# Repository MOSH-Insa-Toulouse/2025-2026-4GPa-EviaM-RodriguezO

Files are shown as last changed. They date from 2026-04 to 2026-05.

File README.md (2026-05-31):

# 2025-2026-4GPa-EviaM-RodriguezO

# Projet Capteur
Dans le cadre du UF « Du capteur au banc de test », ce travail doit concevoir et mettre en œuvre un système de mesure de déformation par un capteur en graphite, lowtech, et comparer son débrouillement à un autre capteur commercial.
Le principe de fonctionnement du capteur en graphite est expliqué comme: La mine de crayon est déposée mécaniquement à la surface du papier, où elle s’insère partiellement dans sa structure poreuse. Cette opération conduit à la formation d’une piste conductrice constituée de particules de graphite dispersées au sein des fibres cellulosiques du papier, le liant jouant principalement un rôle isolant. L’ensemble des particules établit un réseau conducteur dont la continuité dépend du nombre de contacts électriques entre les grains de graphite. Le état du capteur dédnad, la géométrie dépend de la manière dont on s'en sert: une traction tend à éloigner les particules et à réduire les points de contact, tandis qu’une compression favorise leur rapprochement et augmente les connexions conductrices. Ces variations de connectivité se traduisent par une modification mesurable de la résistance électrique de la piste.
La figure suivante illustre, dans la partie c), le fonctionnement du réservoir de graphite sur le feuille:
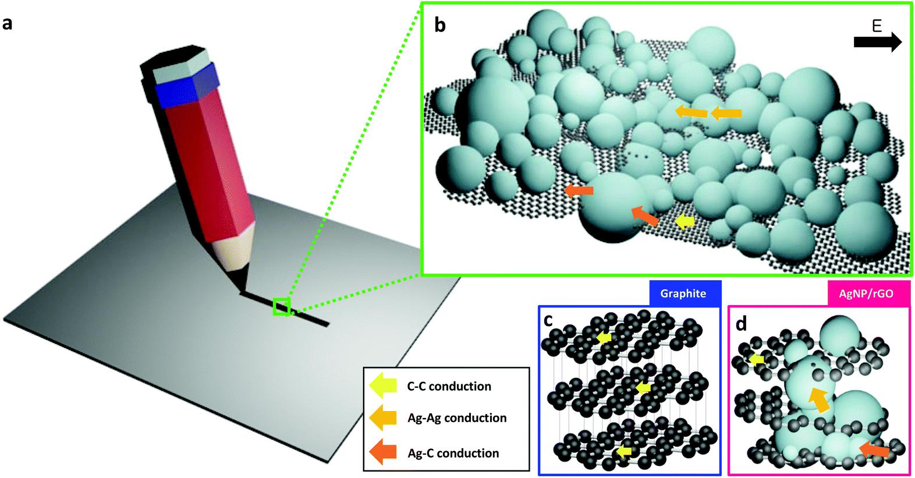
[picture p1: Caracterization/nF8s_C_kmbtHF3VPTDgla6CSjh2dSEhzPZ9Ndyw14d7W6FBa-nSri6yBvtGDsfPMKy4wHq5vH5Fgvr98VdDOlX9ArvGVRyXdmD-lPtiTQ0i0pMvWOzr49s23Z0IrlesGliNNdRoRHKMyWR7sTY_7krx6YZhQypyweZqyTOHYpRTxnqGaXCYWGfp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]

<p align="center">
Répresentation du graphite
</p>
## Objectifs du projet
- Concevoir et réaliser un shield Arduino intégrant un capteur de contrainte en graphite de conception simple afin d'en déterminer les caractéristiques.
- Concevoir un circuit électronique analogique capable de transmettre des données via un microcontrôleur à une application Android, ainsi que la mise en place d'un banc d'essai.
- Élaboration de la datasheet du capteur.

## Contexte
Nous avons fabriqué un capteur de déformation en exploitant la conductivité d'une couche de graphite appliquée sur une feuille de papier, créant ainsi un capteur grâce aux propriétés granulaires acquises qui dépendent également de la composition du crayon.

Lorsque le capteur est comprimé, la résistance diminue en raison de la proximité des molécules de graphite, ce qui augmente la conductivité. Lorsqu'il est étiré, c'est l'inverse qui se produit, ce qui augmente la résistance.

C'est sur la base de ce comportement que l'on cherche à déduire l'angle d'inclinaison afin de connaître et de rendre compte des caractéristiques du capteur.

Ce projet est basé du travail trouvé dans: Lin, CW, Zhao, Z., Kim, J. et al. (2014); Nature, "Pencil Drawn Strain Gauges and Chemiresistors on Paper".

## Livrables

### KiCad
Pour créer la carte qui nous permettrait de disposer de notre circuit, il a fallu réaliser la conception à l'aide du logiciel KiCad, en tenant compte de tous les composants et en utilisant les connexions convenues en cours.


<p align="center">
Schéma du circuit sur KiCad.
</p>

Après avoir déterminé les connexions du circuit, nous avons pu passer à la conception du circuit imprimé, qui devait tenir compte de certains aspects tels que l'optimisation de l'espace, la largeur minimale des pistes tant pour la transmission des données que pour l'alimentation, la résolution possible lors de l'impression, ainsi que la disposition des composants afin d'éviter d'avoir à souder trop de ponts.


<p align="center">
Dessin du circuit imprimé sur KiCad.
</p>

Voir la documentation dans le dossier **Fichiers Kicad**

### Shield
Le modèle 3D du système créé, y compris sa couverture, est présenté dans l'image suivante.


<p align="center">
Système pret pour être implementé
</p>

Afin de mieux présenter les composants, nous allons nous appuyer sur la figure suivante, qui nous permet de voir tous les éléments qui composent le projet, à commencer par le microcontrôleur Arduino, qui assure la conversion des signaux analogiques en signaux numériques ainsi que le contrôle et la coordination des différentes fonctions ; le capteur low-tech qui sera mis à l'épreuve ; le capteur commercial, afin de pouvoir le comparer à un produit en principe mieux adapté à l'objectif ; l'encodeur, qui permet de sélectionner les fonctions et de les commander manuellement; l'écran OLED, qui nous permet de disposer d'une interface pour sélectionner et contrôler manuellement les fonctions, ainsi que pour afficher les données transmises par les capteurs ; et enfin, le module Bluetooth, qui permet de recevoir les données des capteurs et de les afficher dans l'application mobile.



<p align="center">
Dispositif sans boîtier de protection
</p>

Ces images peuvent être visualisées dans le dossier **3D designs**

### Code Arduino
Le code Arduino a pour but de permettre à l'utilisateur d'interagir avec tous les composants du système : 

- Le contrôle du servomoteur
  - Modification de l'angle d'inclinaison.
  
- Le réglage du potentiomètre numérique
  - Ajustement du gain du système.

- L'affichage local
  - Visualisation en temps réel des données sur l'écran OLED.

- La communication Bluetooth
  - Transmission des données des deux capteurs vers l'application mobile.
 > [!TIP]
> Vous pouvez utiliser l'encodeur numérique pour naviguer dans le menu de l'écran OLED et sélectionner les paramètres souhaités. Cliquez pour accéder au menu de votre choix et maintenez le bouton de l'encodeur enfoncé pour revenir au menu principal.
### Logiciel pour portables
Grâce à la plateforme MIT App Inventor, nous avons conçu une application dont la fonction principale était de pouvoir recevoir et représenter graphiquement les données captées par un ou les deux capteurs simultanément, ainsi que de pouvoir envoyer des données pour commander à la fois le servomoteur et le potentiomètre numérique ; toutefois, l'envoi de données n'a pas eu lieu.
<p align="center">
 
</p>
<p align="center">
Application crée, face-avant au démarrage / avec les fonctions.
</p>

Le code des blocs derrière l'interface est visible sur les images suivantes.



<p align="center">
Bloques de code.
</p>

Voir la documentation dans le dossier **Application Mobile**.
### Datasheet
Toutes les spécifications du capteur, sa caractérisation et sa simulation dans le logiciel LTspice sont disponibles dans la fiche technique: [Datasheet](Datasheets/Datasheet_MOSH_EN.pdf)
# Caractérisation du système 
La réponse du capteur à la manipulation a été caractérisée à l'aide de deux types différents de feuilles de graphite : de type HB et de type 3HB. En faisant varier la résistance du potentiomètre, on a constaté que la tension maximale du capteur était atteinte lorsque le potentiomètre avait un gain de 225. 
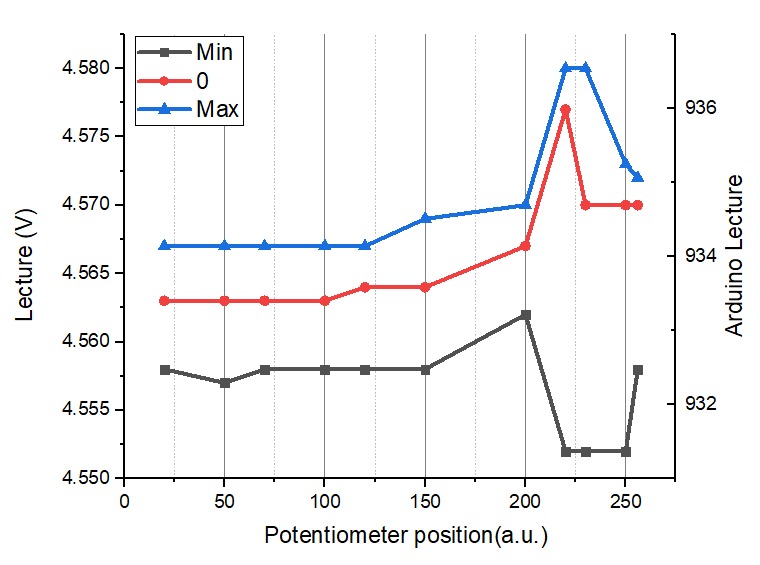
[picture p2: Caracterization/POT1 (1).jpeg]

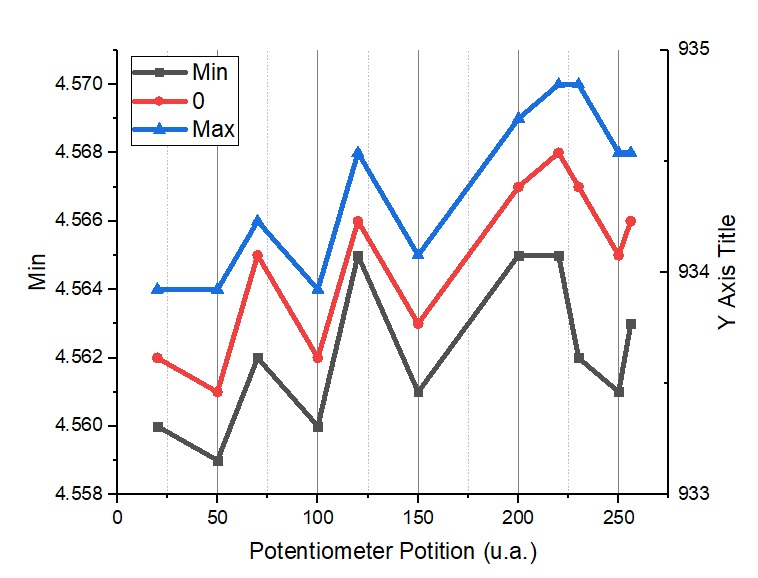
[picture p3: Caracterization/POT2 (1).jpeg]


<p align="center">
Caractérisation du capteur.
</p>

## Conclusion 
Ce projet nous a permis de voir concrètement comment exploiter un phénomène physique pour mesurer un changement au sein d'un système ; en recourant à des moyens simples et en tirant parti de propriétés microscopiques, nous avons pu concevoir un dispositif qui nous a permis de collecter et de traiter des données de manière relativement simple.

Cependant, le projet a également mis en évidence les limites de l'utilisation de ce type de systèmes low-tech, à commencer par la capacité à reproduire les mêmes résultats, car il existe un grand nombre de variables à prendre en compte, telles que l'état du papier, la composition du graphite, la qualité du trait tracé ; toutes ces variables affectent le fonctionnement et l'étalonnage du capteur, et sont difficiles à normaliser manuellement. Et, parallèlement, certaines de ces variables étant très sensibles à l'utilisation, cela finit par nuire à la fiabilité des données recueillies au fil du temps-
Pour toute question concernant les caractéristiques du capteur ou en cas de problèmes techniques, n'hésitez pas à contacter :
- Octavio Rodriguez : orodriguez-r@insa.toulouse.fr
- Manuel Evia : mevia@insa-toulouse.fr

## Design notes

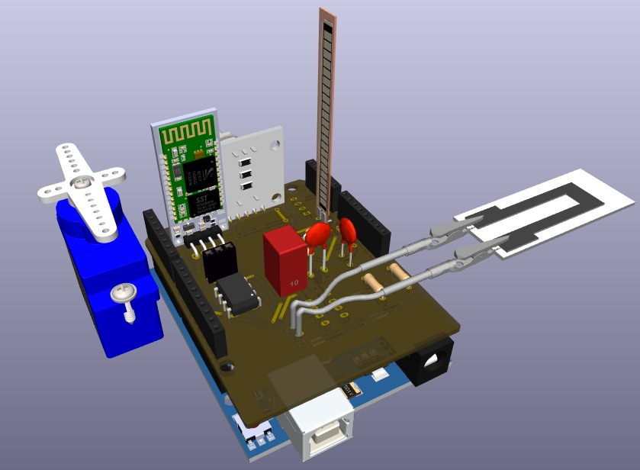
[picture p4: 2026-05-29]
3D designs/Shield/Système.png

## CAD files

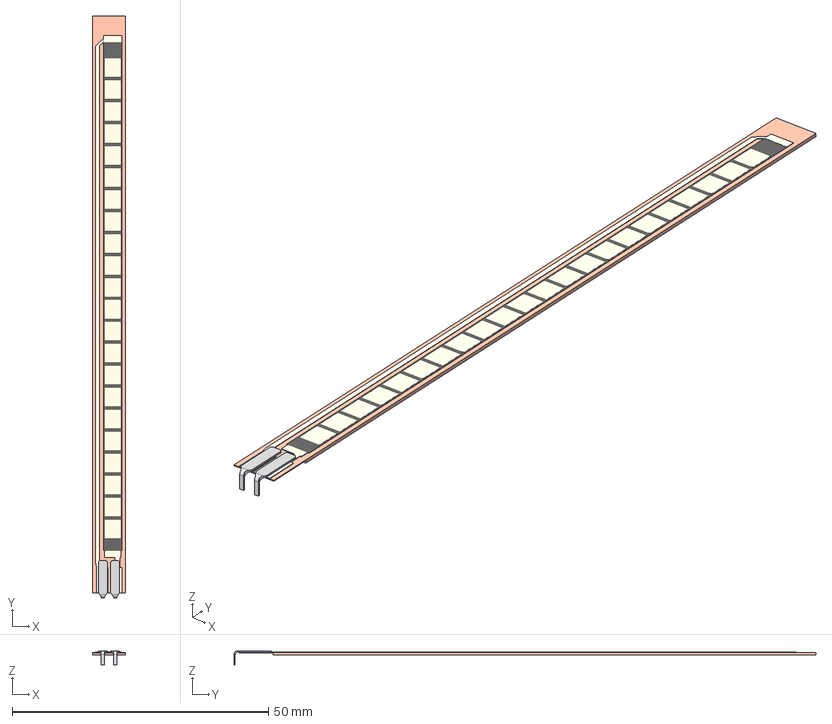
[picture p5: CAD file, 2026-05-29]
3D designs/Composants/FS-L-0095-103-ST - Assembly.stp
6.45 x 113.5 x 2.77 mm
FS-L-0095-103-ST - Base
FS-L-0095-103-ST - Top

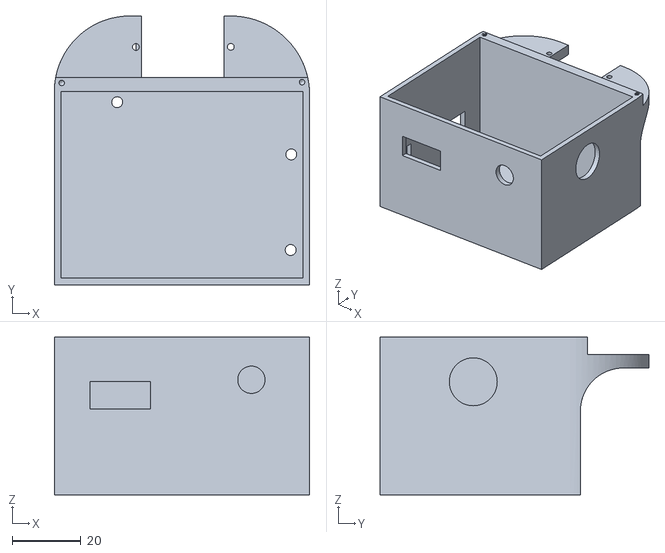
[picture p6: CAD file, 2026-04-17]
3D designs/Shield/Body_Shield (1).stl
74.5 x 78.5 x 46.0

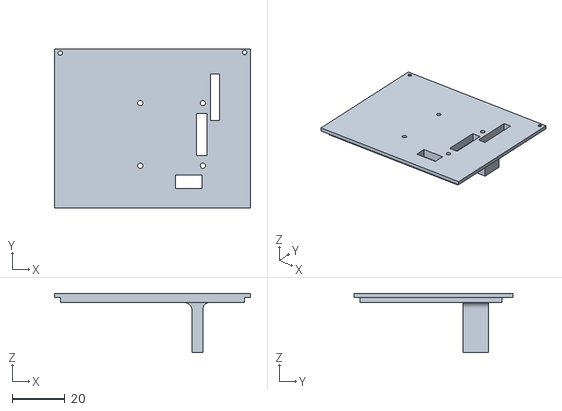
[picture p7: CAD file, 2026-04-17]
3D designs/Shield/Roof_Shield (1).stl
74.5 x 60.5 x 22.5

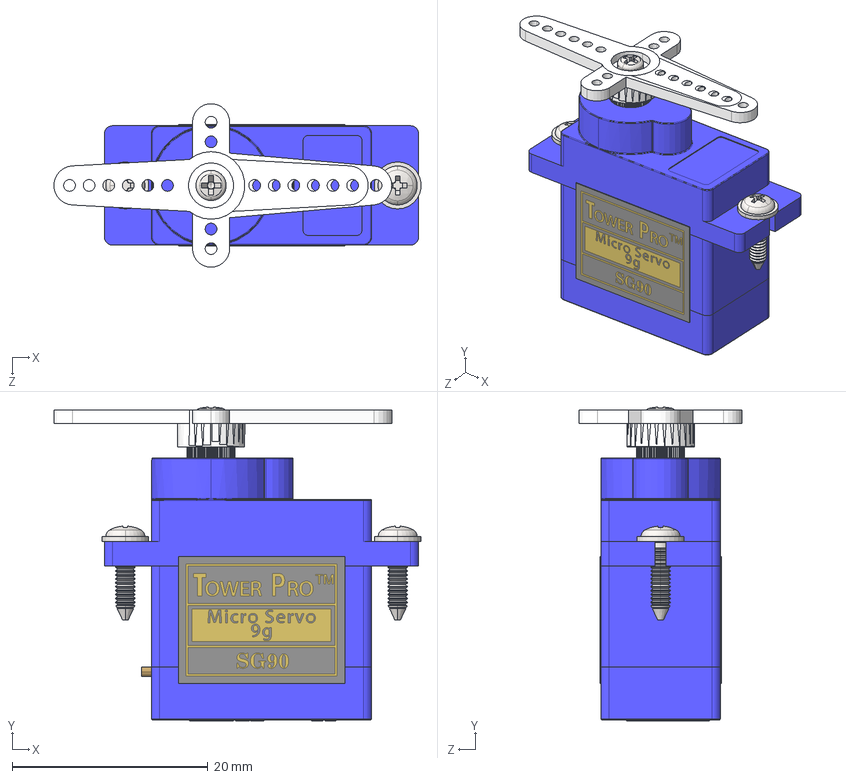
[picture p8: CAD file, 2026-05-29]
3D designs/Composants/SG90 - Micro Servo 9g - Tower Pro.STEP
37.5 x 32.0 x 16.7 mm
SG90 - Micro Servo 9g - Tower Pro.1_Pe㌢
SG90 - Micro Servo 9g - Tower Pro.2_Pe㌢
SG90 - Micro Servo 9g - Tower Pro.3_Pe㌢
SG90 - Micro Servo 9g - Tower Pro.4_Pe㌢
SG90 - Micro Servo 9g - Tower Pro.5_BS EN ISO 7045 - M2 x 8 - Z - 8S x 2
SG90 - Micro Servo 9g - Tower Pro.6_BS EN ISO 7045 - M2 x 4 - Z - 4S

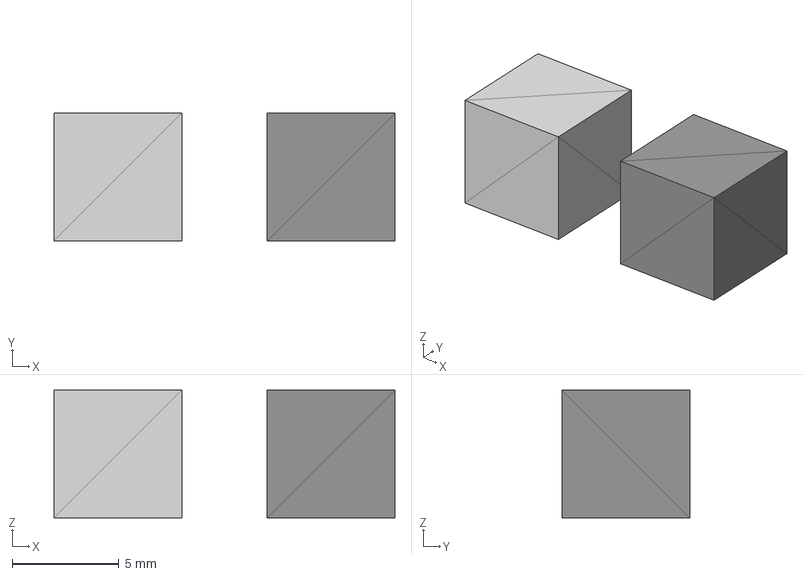
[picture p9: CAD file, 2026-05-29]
3D designs/Composants/Cuerpo1.step
16.0 x 6.00 x 6.00 mm

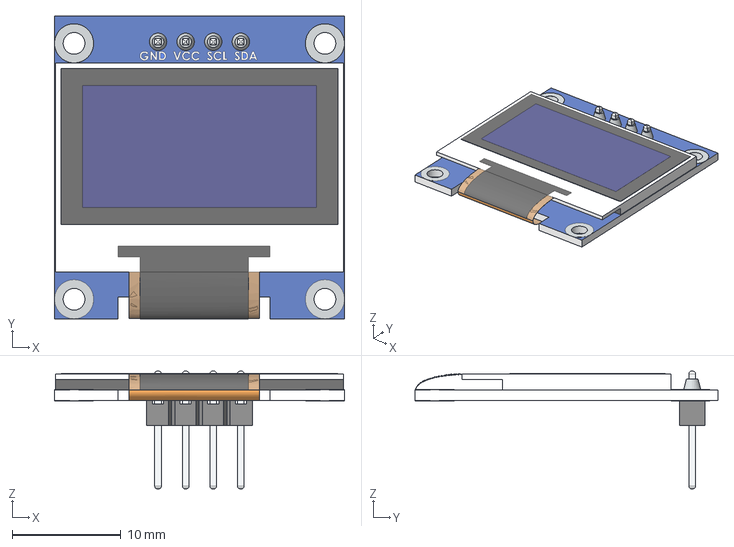
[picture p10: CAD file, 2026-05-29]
3D designs/Composants/OLED-128x64-0.96.step
26.7 x 27.9 x 10.8 mm

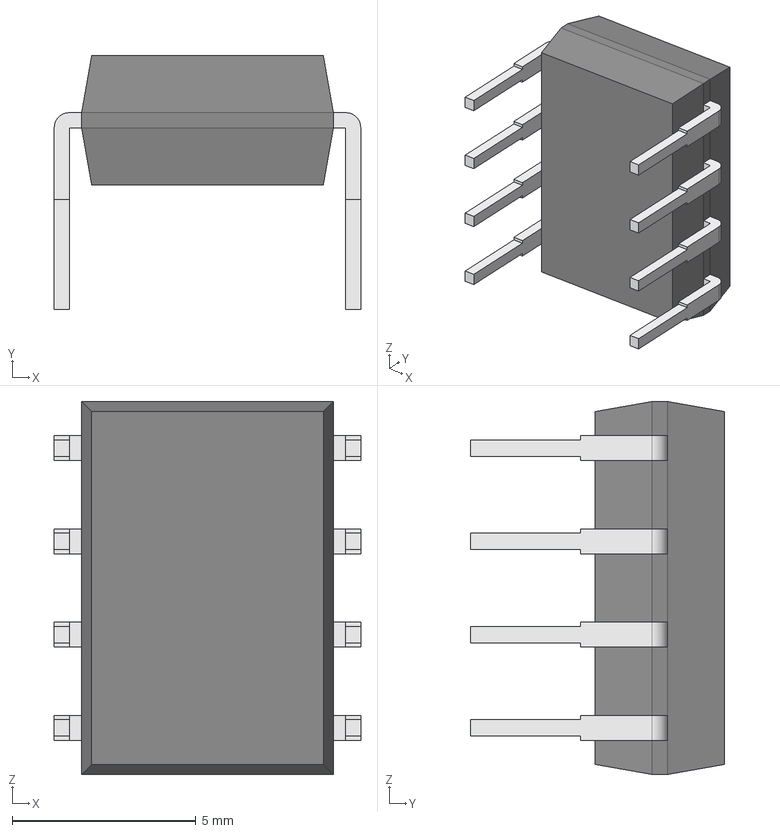
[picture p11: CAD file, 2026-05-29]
3D designs/Composants/LTC1050CN8.step
8.35 x 6.93 x 10.2 mm
Body001 (Mirror #1) x 5

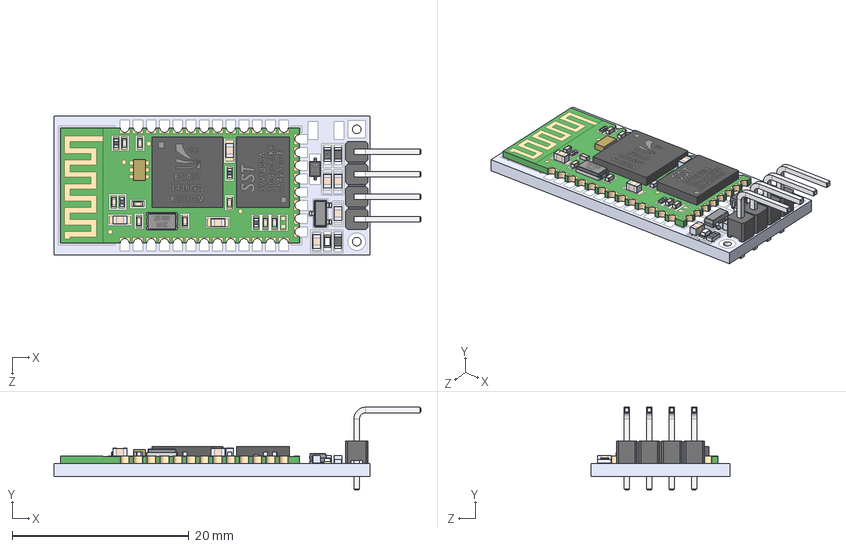
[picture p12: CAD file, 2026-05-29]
3D designs/Composants/HC06_Modulo.STEP
41.5 x 9.36 x 15.8 mm
HC05_Pcb
HC05_06
C0603 x 7
R0402_По умолчанию x 4
C0402 x 9
QSMD7.0x5.0x1.3
Led 0603 Smd
R0603 222_По умолчанию x 2
R0603 103_По умолчанию
SOT23-3
SOD323 S4
Pines_90_4p

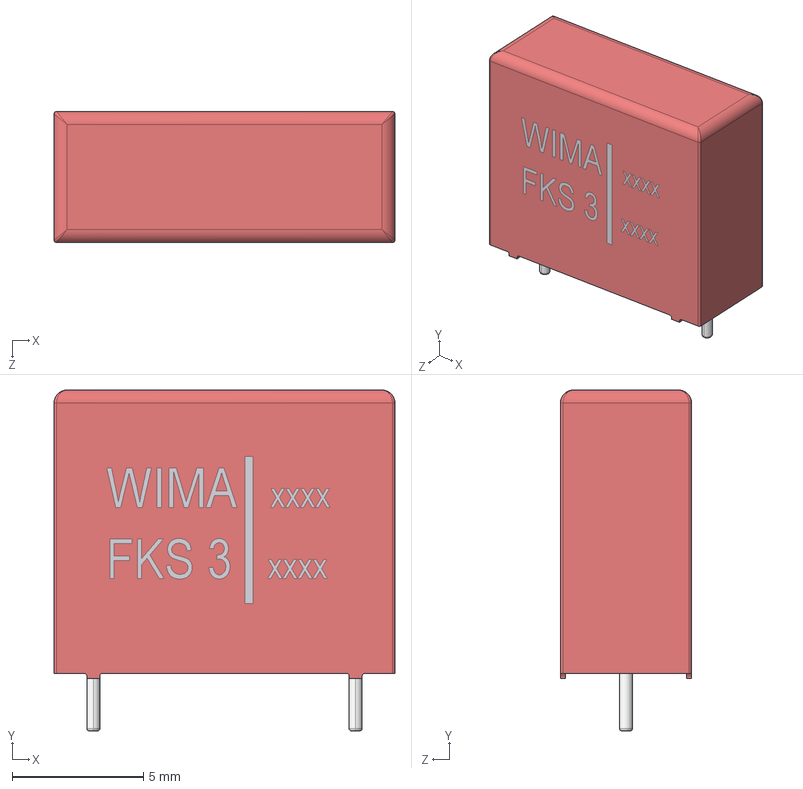
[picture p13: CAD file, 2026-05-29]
3D designs/Composants/FKS3 PCM10 W5 H11 L13.STEP
13.0 x 13.0 x 5.00 mm

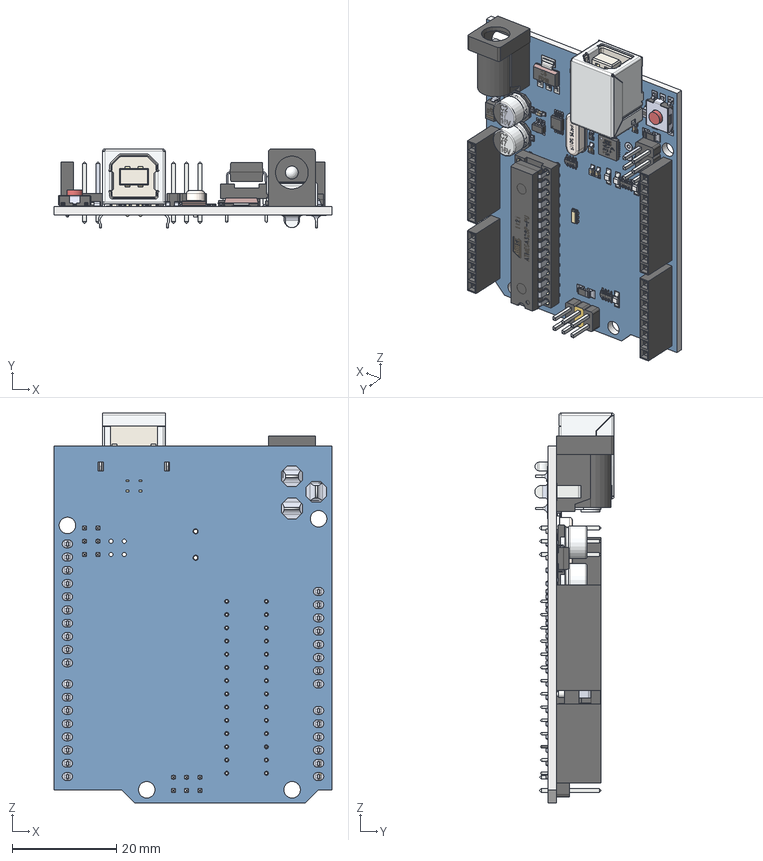
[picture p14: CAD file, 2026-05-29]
3D designs/Composants/Arduino Uno.step
53.3 x 15.2 x 74.9 mm

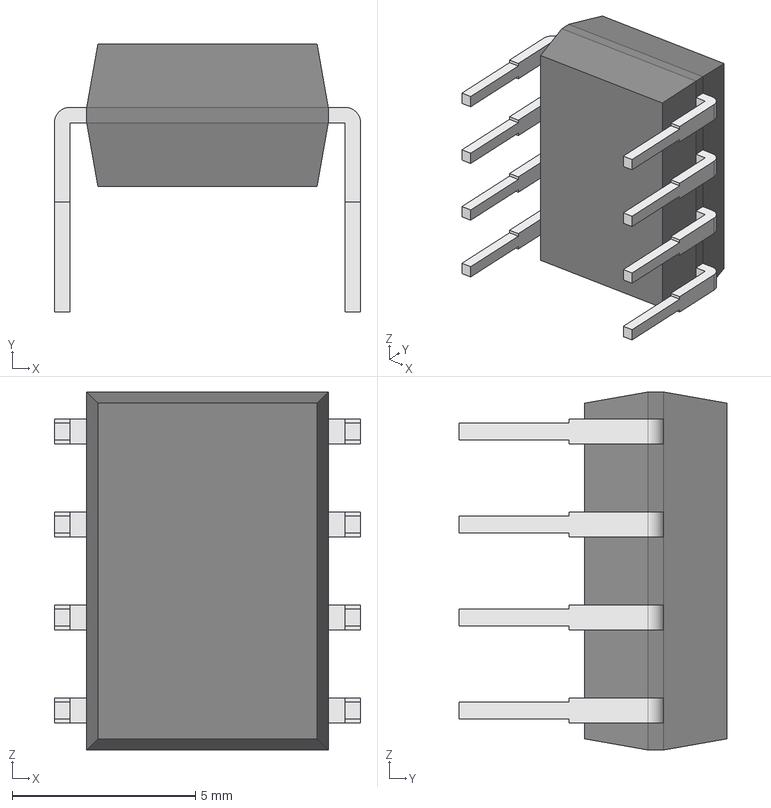
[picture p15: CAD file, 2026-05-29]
3D designs/Composants/MCP41010-I_P.step
8.37 x 7.32 x 9.78 mm
Body001 (Mirror #1) x 5

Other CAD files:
3D designs/Composants/CapteurGraphite.step
3D designs/Composants/Cuerpo1.stl

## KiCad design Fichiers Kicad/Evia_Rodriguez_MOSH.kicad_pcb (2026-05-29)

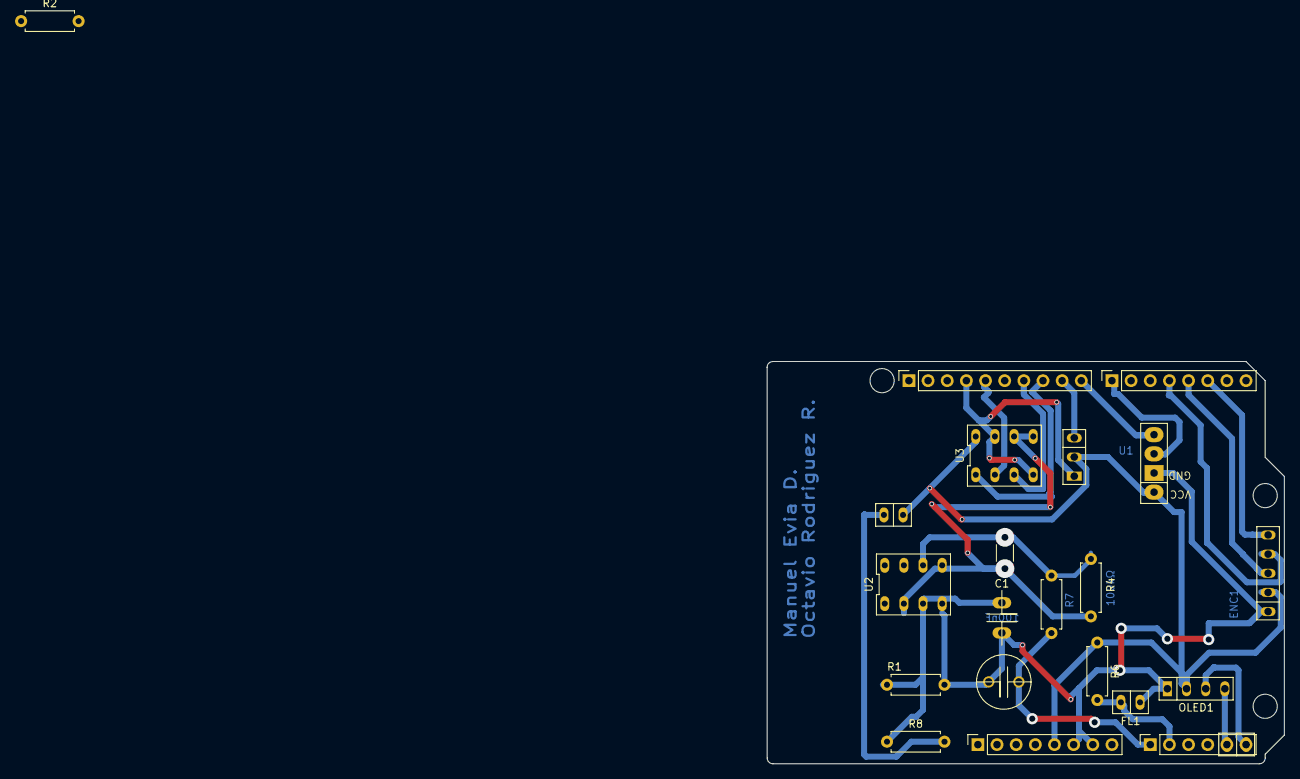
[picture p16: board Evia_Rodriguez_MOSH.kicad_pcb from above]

Board: 2 copper layers, 68.6 x 53.3 mm, 25 parts (0 on the bottom side), 19 nets.

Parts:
C1, C3: 100nF; CPA_2
C2: 1µF; C_1808_4520Metric
ENC1: SIP-5
FL1, FL1#2: SIP-2
GS1: SIP-2
J1: Power; PinSocket_1x08_P2.54mm_Vertical
J2: Digital/PWM; PinSocket_1x10_P2.54mm_Vertical
J3: Analog; PinSocket_1x06_P2.54mm_Vertical
J4: Digital/PWM; PinSocket_1x08_P2.54mm_Vertical
M1: Motor_Servo; SIP-3
MH1, MH3, MH4: MountingHole_3.2mm
OLED1: SIP-4
R1, R4: 100kΩ; R_Axial_DIN0207_L6.3mm_D2.5mm_P7.62mm_Horizontal
R2, R6, R8: 10kΩ; R_Axial_DIN0207_L6.3mm_D2.5mm_P7.62mm_Horizontal
R7: 1kΩ; R_Axial_DIN0207_L6.3mm_D2.5mm_P7.62mm_Horizontal
U1: Bluetooth_HC05
U2: LTC1050ACN8_PBF; MPC41010
U3: MCP41010; MPC41010

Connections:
+5V: ENC1.2 (+), GS1.1, J1.5, M1.2 (+), OLED1.2 (VCC), R6.1, U1.1 (VCC), U2.7 (V+), U3.8 (VDD)
A1: FL1#2.1, J3.2, R6.2
A4: J3.5, OLED1.4 (SDA)
A5: J3.6, OLED1.3 (SCL)
ADC: C3.1, J3.1, R7.2
D2: ENC1.5 (CLK), J4.6
D3: ENC1.3 (SW), J4.5
D4: ENC1.4 (DT), J4.4
D7: J4.1, U1.3 (TXD)
D8: J2.10, U1.4 (RXD)
D9: J2.9, M1.1 (PWM)
D10: J2.8, U3.1 (~CS)
D11: J2.7, U3.3 (SI)
D13: J2.5, U3.2 (SCK)
GND: C1.2, C3.2, ENC1.1 (GND), FL1#2.2, J1.6, J1.7, J2.4, M1.3 (-), OLED1.1 (GND), R1.2, U1.2 (GND), U2.4 (V-), U3.4 (VSS), U3.7 (PB0)
unnamed: GS1.2, R8.2
unnamed: C1.1, R1.1, R8.1, U2.3 (+IN)
unnamed: C2.2, R4.2, R7.1, U2.6 (OUT)
R2+: C2.1, R4.1, U2.2 (-IN), U3.5 (PA0), U3.6 (PW0)

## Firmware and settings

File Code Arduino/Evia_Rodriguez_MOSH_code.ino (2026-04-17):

#include <Adafruit_SSD1306.h>
#include <SPI.h>
#include <Servo.h>
#include <Wire.h>
#include <SoftwareSerial.h>


/* PINOUT */
#define PIN_OPAMP A0
#define PIN_FLEX  A1
#define ENC_CLK   2
#define ENC_SW    3
#define ENC_DT    4
#define BT_STATE  6  
#define PIN_SERVO 9
#define PIN_CS    10 

#define MCP_WRITE 0b00010001
#define GRAPH_X0 20   // 
#define GRAPH_Y0 0    // Variables nécessaires pour définir les dimensions 
#define GRAPH_W 108   // des graphiques en fonction de la taille de l'écran OLED
#define GRAPH_H 54    
/* ------------------ OBJETS-----------*/
SoftwareSerial mySerial(7,8);
Servo servoMotor;
Adafruit_SSD1306 display(128, 64, &Wire, -1);
String inputBuffer = "";
String serialBuffer = "";

volatile long encoderPos = 0;
volatile int lastStateCLK;
int menuIndex = 0;
int graphX = 0;
int lastY = 32;
int servoPos = 0;
int potValue = 128;  


enum Mode {
  MENU,
  ANALOG_A0,
  ANALOG_A1,
  SERVO_MODE,
  POT_MODE,
  BT_MODE,
  //MORSE_MODE
};

Mode currentMode = MENU;

/* Servo & Pot */
bool btWasEverConnected = false;
bool receivingCommand = false;
bool lastButtonStateMorse = false;
bool resetTriggered = false;
bool btConnected = false;
bool lastBtState = false;
bool buttonState = false;
bool lastButtonState = false;
bool click = false;

unsigned long pressStartTime = 0;
long lastEnc = 0;/* Encoder */

/*-------------Function Potentiomètre------------------*/
void writePot(byte value) {
  digitalWrite(PIN_CS, LOW);
  SPI.transfer(MCP_WRITE);
  SPI.transfer(value);
  digitalWrite(PIN_CS, HIGH);
}
/*AAAAAAAA*/
void handleSerial() {  //Function pour détecter des commands vers l'arduino

  while (Serial.available() || mySerial.available()) {

    char c;

    if (Serial.available()) c = Serial.read();
    else c = mySerial.read();

    /*-------- SERVO COMMANDS FUNCTION --------*/
    if (c == 'S') {

      // Esperar siguiente carácter
      while (!Serial.available() && !mySerial.available());
      if (Serial.available()) c = Serial.read();
      else c = mySerial.read();
      if (c == '1') {
        servoPos -= 5;
      }
      else if (c == '2') {
        servoPos += 5;
      }

      servoPos = constrain(servoPos, 0, 180);
      servoMotor.write(servoPos);
      Serial.print("Servo -> ");
      Serial.println(servoPos);
      continue;
    }

    // -------- MENU MODE --------
    if (c == 'M') {
      inputBuffer = "M";
      continue;
    }

    if (inputBuffer.length() == 1) {
      if (c >= '1' && c <= '5') {

        switch (c) {
          case '1': currentMode = ANALOG_A0; break;
          case '2': currentMode = ANALOG_A1; break;
          case '3': currentMode = SERVO_MODE; break;
          case '4': currentMode = POT_MODE; break;
          case '5': currentMode = BT_MODE; break;
        }

        graphX = 0;
        encoderPos = 0;
        lastEnc = 0;

        Serial.print("Changé à M");
        Serial.println(c);
      }

      inputBuffer = "";
    }
  }
}
/* ---------------------Function ENCODEUR--------------*/
void doEncoder() {      
  int currentStateCLK = digitalRead(ENC_CLK);
  if (currentStateCLK != lastStateCLK) {
    if (digitalRead(ENC_DT) != currentStateCLK) encoderPos++;
    else encoderPos--;
  }
  lastStateCLK = currentStateCLK;
}
void setup() {
  mySerial.begin(9600);
  Serial.begin(9600);
  pinMode(7,INPUT);
  pinMode(8,OUTPUT);

  pinMode(ENC_CLK, INPUT_PULLUP);
  pinMode(ENC_DT, INPUT_PULLUP);
  pinMode(ENC_SW, INPUT_PULLUP);


  lastStateCLK = digitalRead(ENC_CLK);
  attachInterrupt(digitalPinToInterrupt(ENC_CLK), doEncoder, CHANGE);

  servoMotor.attach(PIN_SERVO);
  pinMode(BT_STATE, INPUT);
  pinMode(PIN_CS, OUTPUT);
  digitalWrite(PIN_CS, HIGH);
  SPI.begin();
  display.begin(SSD1306_SWITCHCAPVCC, 0x3C);
}

/* ===================== LOOP ===================== */
void loop() {
bool currentBtState = digitalRead(BT_STATE); //Function pour détecter si le module BT et connecté à le portable
if (currentBtState && !lastBtState) {
  if (!btConnected) {
    btConnected = true;
  if (!btWasEverConnected) {
    btWasEverConnected = true;
    }
  }
}
// Détecter connexion
if (!currentBtState && lastBtState) {
  btConnected = false;
}

lastBtState = currentBtState;
handleSerial(); //FIN DE DÉTECTION BT

  long currentEnc;
  noInterrupts();
  currentEnc = encoderPos;
  interrupts();
  int delta = currentEnc - lastEnc;
  lastEnc = currentEnc;
  buttonState = digitalRead(ENC_SW) == LOW;
  unsigned long now = millis();
  if (buttonState && !lastButtonState) {
    pressStartTime = now;
    resetTriggered = false;
  }
  if (!buttonState && lastButtonState) {
    if (!resetTriggered) click = true;
  }
  switch (currentMode) {

    case MENU: {
      menuIndex += delta;
      menuIndex = constrain(menuIndex, 0, 4);

      if (click) {
        click = false;
        switch (menuIndex) {
          case 0: currentMode = ANALOG_A0; break;
          case 1: currentMode = ANALOG_A1; break;
          case 2: currentMode = SERVO_MODE; break;
          case 3: currentMode = POT_MODE; break;
          case 4: currentMode = BT_MODE; break;
        }
      }

      display.clearDisplay();
      display.drawRect(0,0,128,64,SSD1306_WHITE);
      display.setTextSize(1);
      display.setTextColor(SSD1306_WHITE);
      if (btConnected) {
   display.setCursor(60, 5); // esquina superior derecha aprox
    display.print("BT Connect!");
}
else if(!btConnected) {
  display.setCursor(60, 5);
  display.print("No BT !");
}
      const char* items[5] = {
        "A0",
        "A1",
        "Servo",
        "Pot",
        "Bluetooth",
      };

      for (int i = 0; i < 5; i++) {
        display.setCursor(10, 10 + i * 10);
        if (i == menuIndex) display.print(">");
        display.print(items[i]);
      }

      display.display();
      break;
    }

  case ANALOG_A0: {
int raw = analogRead(A0);
  int y = map(raw, 880, 905, GRAPH_Y0 + GRAPH_H, GRAPH_Y0);

  // Démarragesu graph 
  if (graphX == 0) {
    display.clearDisplay();
    // AXE X
    display.drawLine(GRAPH_X0, GRAPH_Y0 + GRAPH_H, GRAPH_X0 + GRAPH_W, GRAPH_Y0 + GRAPH_H, SSD1306_WHITE);
    // AXE Y
    display.drawLine(GRAPH_X0, GRAPH_Y0, GRAPH_X0, GRAPH_Y0 + GRAPH_H, SSD1306_WHITE);
    // TICKS Y
    for (int i = 0; i <= GRAPH_H; i += 10) {
      display.drawPixel(GRAPH_X0, GRAPH_Y0 + i, SSD1306_WHITE);
    }
    // TICKS X
    for (int i = 0; i <= GRAPH_W; i += 10) {
      display.drawPixel(GRAPH_X0 + i, GRAPH_Y0 + GRAPH_H, SSD1306_WHITE);
    }
    // ===== Type du text =====
    display.setTextSize(1);
    display.setTextColor(SSD1306_WHITE);
    // Caption
    display.setCursor(60, 0);
    display.print("A0");

    // "tiempo" abajo
    display.setCursor(50, 58);
    display.print("tiempo");
    //
    display.setTextSize(1);
  display.setCursor(0, 0);
  display.print("5V");

  display.setCursor(0, 24);
    display.print("2.5V");

    display.setCursor(0, 52);
    display.print("0V");


  }
  // Dibujar señal
  if (graphX > 0) {
    display.drawLine(
      GRAPH_X0 + graphX - 1, lastY,
      GRAPH_X0 + graphX, y,
      SSD1306_WHITE
    );
  }
  lastY = y;
  display.display();
  graphX++;
  if (graphX >= GRAPH_W) {
    graphX = 0;
  }
  if (click) {
    click = false;
    graphX = 0;
    display.clearDisplay();
    currentMode = MENU;
  }
  break;
}
    case ANALOG_A1: {
      const float VCC= 5; 
      const float R_DIV= 10000; 
      const float flatresistance = 25000.0; 
      const float bendresistance = 100000.0;

int boxWidth = 50;
int boxHeight = 16;
int boxX = 128 - boxWidth;  // Boite de text
int boxY = 25;
int raw2 = analogRead(A1);
// Conversion lecture -> Tension
float Vflex = raw2*VCC/1023.0;
float Rflex = R_DIV *(VCC/Vflex-1.0);
float angle = -100*Vflex+391;
  int y = map(raw2, 580, 1003, GRAPH_Y0 + GRAPH_H, GRAPH_Y0);
  // Démarrage du graph
  if (graphX == 0) {
    display.clearDisplay();

    // EJE X
    display.drawLine(GRAPH_X0, GRAPH_Y0 + GRAPH_H, GRAPH_X0 + GRAPH_W, GRAPH_Y0 + GRAPH_H, SSD1306_WHITE);
    // EJE Y
    display.drawLine(GRAPH_X0, GRAPH_Y0, GRAPH_X0, GRAPH_Y0 + GRAPH_H, SSD1306_WHITE);
    // TICKS Y
    for (int i = 0; i <= GRAPH_H; i += 10) {
      display.drawPixel(GRAPH_X0, GRAPH_Y0 + i, SSD1306_WHITE);
    }

    // TICKS X
    for (int i = 0; i <= GRAPH_W; i += 10) {
      display.drawPixel(GRAPH_X0 + i, GRAPH_Y0 + GRAPH_H, SSD1306_WHITE);
    }
    display.drawRect(boxX, boxY, boxWidth, boxHeight, SSD1306_WHITE);
    display.setTextSize(1);
    display.setTextColor(SSD1306_WHITE);

// "Valeur Actuel du angle"
    display.setCursor(boxX + 3, boxY + 2);
    display.print("A:");
    display.print((int)angle);
        // ===== Propietés du text =====
        display.setTextSize(1);
        display.setTextColor(SSD1306_WHITE);

    // Caption du graph
    display.setCursor(60, 0);
    display.print("A1");

    // "temps"
    display.setCursor(50, 58);
    display.print("tiempo");
    display.setTextSize(1);
    display.setCursor(0, 0);
    display.print("-90°");
    display.setCursor(0, 24);
    display.print("0°");
    display.setCursor(0, 52);
    display.print("90°");
  }
  // Dibujar señal
  if (graphX > 0) {
    display.drawLine(
      GRAPH_X0 + graphX - 1, lastY,
      GRAPH_X0 + graphX, y,
      SSD1306_WHITE
    );
  }
  lastY = y;
  display.display();
  graphX++;

  if (graphX >= GRAPH_W) {
    graphX = 0;
  }
  if (click) {
    click = false;
    graphX = 0;
    display.clearDisplay();
    currentMode = MENU;
  }
  break;
}
case SERVO_MODE: {

      servoPos += delta * 2;
      servoPos = constrain(servoPos, 0, 180);
      servoMotor.write(servoPos);

      display.clearDisplay();
      display.setCursor(15,30);
      display.print("Servo: ");
      display.print(servoPos);
      display.display();
      break;
    }
    case POT_MODE: {
      potValue += delta;
      potValue = constrain(potValue, 0, 255);
      writePot(potValue);

      display.clearDisplay();
      display.drawRect(0,0,128,64,SSD1306_WHITE);
      display.setCursor(15,30);
      display.print("Pot: ");
      display.println(potValue);
      display.display();
      break;
    }

case BT_MODE: {
  display.clearDisplay();
  display.drawRect(0,0,128,64,SSD1306_WHITE);
  display.setCursor(20,30);
  display.print("Bluetooth");
  int raw = analogRead(A0);
  int raw2 = analogRead(A1); 
    float voltage = raw * (5.0 / 1023.0);
     mySerial.print(raw);
    mySerial.print("=");
     mySerial.println(raw2);
  delay(200); // evita saturar el BT
  display.display();
  break;
}

  }
  if (buttonState && (now - pressStartTime > 1500) && !resetTriggered) {
  currentMode = MENU;
  resetTriggered = true;

  graphX = 0;
  encoderPos = 0;
  lastEnc = 0;
}
  lastButtonState = buttonState;
 
	  int i = 0; 
	char someChar[32] ={0};
	//when characters arrive over the serial port...

/*	while (Serial.available()) {
	   do{
		someChar[i++] = Serial.read();
		delay(3);		
	   }while (Serial.available() > 0);
	   
	   mySerial.println(someChar); 
	   Serial.println(someChar); 
	}
	while (mySerial.available()) {
		Serial.print((char)mySerial.read());
	}*/

  while (mySerial.available()) {
  Serial.print((char)mySerial.read());
}
}

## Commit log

2026-05-29 Create Modèles 3D pour Kicad
2026-05-29 kicad shcema
2026-05-29 conclusion y alineamiento de imagen de app
2026-05-29 Enhance README with Arduino code functionalities
    Added details about the Arduino code functionalities including servo control, digital potentiometer adjustment, local display, and Bluetooth communication.
2026-05-29 la fin
2026-05-31 Add sensor characterization details to README
    Added characterization section for sensor response and included an image.
2026-05-31 Change image source in README for sensor characterization
    Updated image source for sensor characterization.
2026-05-31 Adjust image sizes in sensor characterization section
    Updated image dimensions for sensor characterization.
2026-05-31 Revise README with new graphite representation and image
    Updated the README to include a new image and modified text regarding the graphite sensor.
